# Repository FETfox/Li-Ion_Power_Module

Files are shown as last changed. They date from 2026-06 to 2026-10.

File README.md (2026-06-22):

## Status

  **RevA** In development (schematic complete, layout pending)

## Key Components

| Function | IC | Notes |
|---|----|----|
| Charger | BQ24074 | USB100/500 + ILIM modes |
| Protection | BQ29728 | OCP/OVP/UVP |
| Fuel Gauge | BQ27427 | Coulomb counter |
| Buck-Boost | TPS63020 | ~1.8-5.5V input, 3.3V/5V output |
| MCU (Smart) | ATtiny3217 | CAN interface logic |
| CAN Controller | MCP2515 | SPI interface |
| CAN Transceiver | SN65HVD230 | ISO11898-2 compliant |

## Usage

Battery powered 5w power supply for projects that use 3v3 or 5v.
The smart version tracks system status and communicates over CAN bus.

## Known Issues / TODOs

- [ ] PCB layout and thermal analysis
- [ ] Publish assembly guide and test procedure

## License

CC0

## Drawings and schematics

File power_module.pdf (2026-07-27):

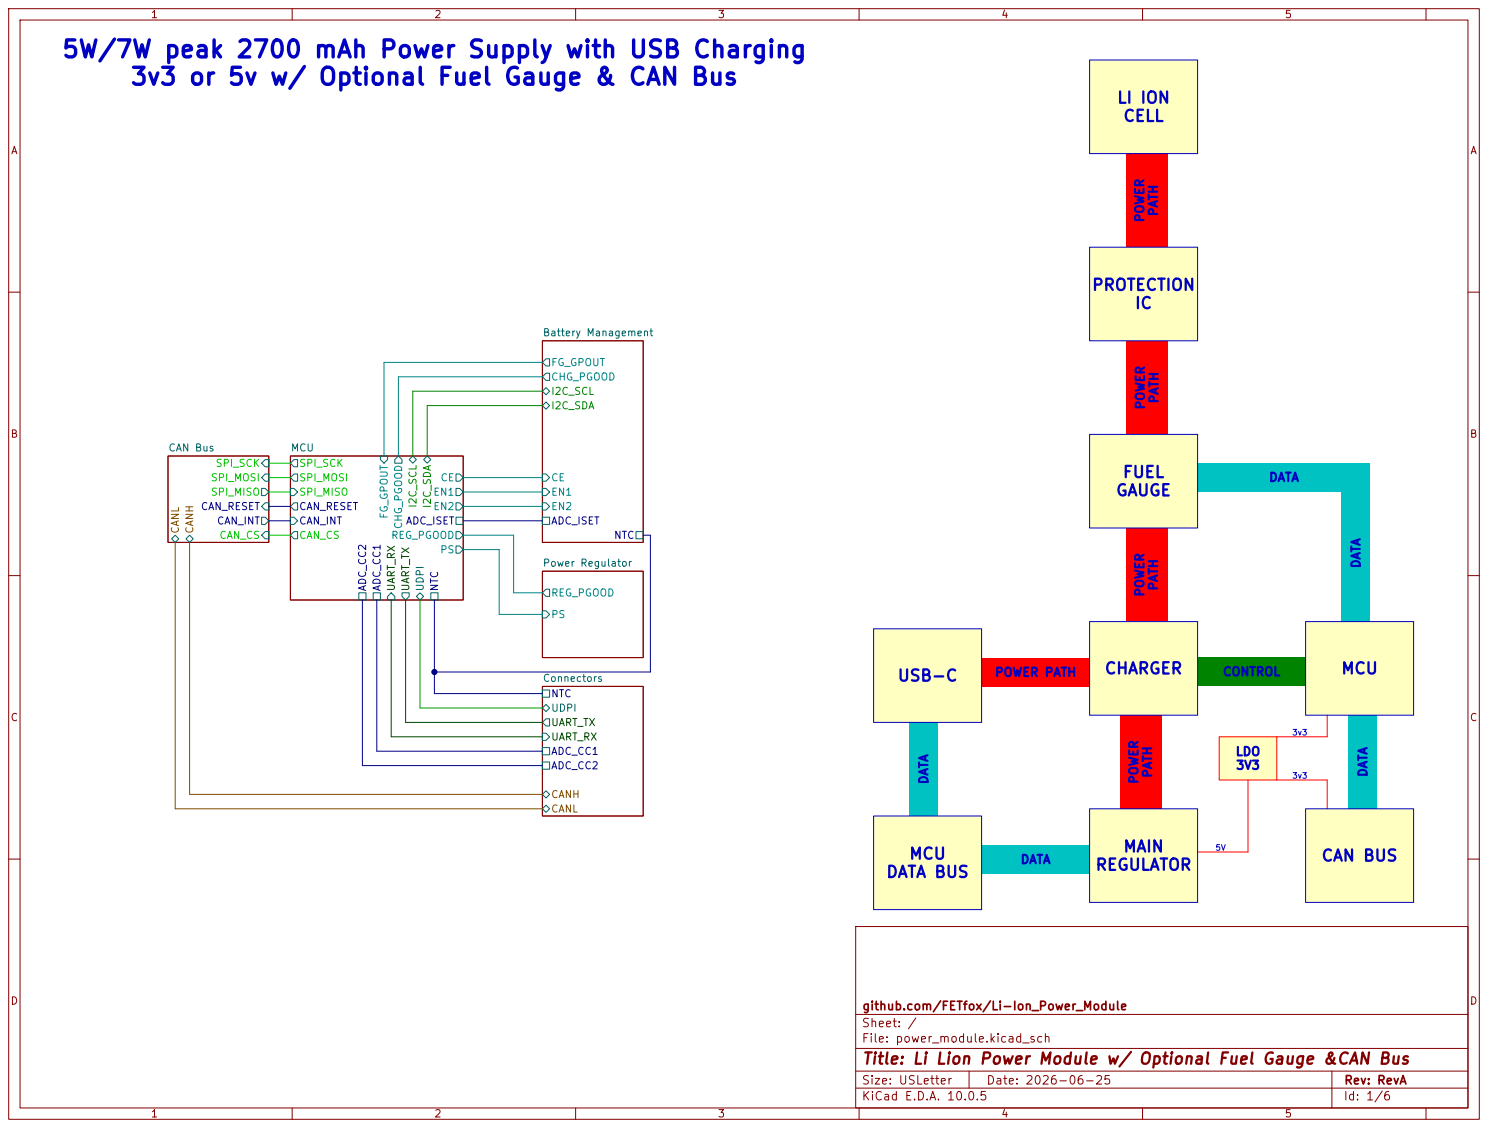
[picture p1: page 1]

5W/7W peak 2700 mAh Power Supply with USB Charging
3v3 or 5v w/ Optional Fuel Gauge & CAN Bus

LI ION
CELLPOWER PATH POWER PATH

Sheet: /
File: power_module.kicad_sch
Title: Li Lion Power Module w/ Optional Fuel Gauge &CAN Bus

Size: USLetter | Rev: RevA
KiCad E.D.A. 10.0.5 | Id: 1/6

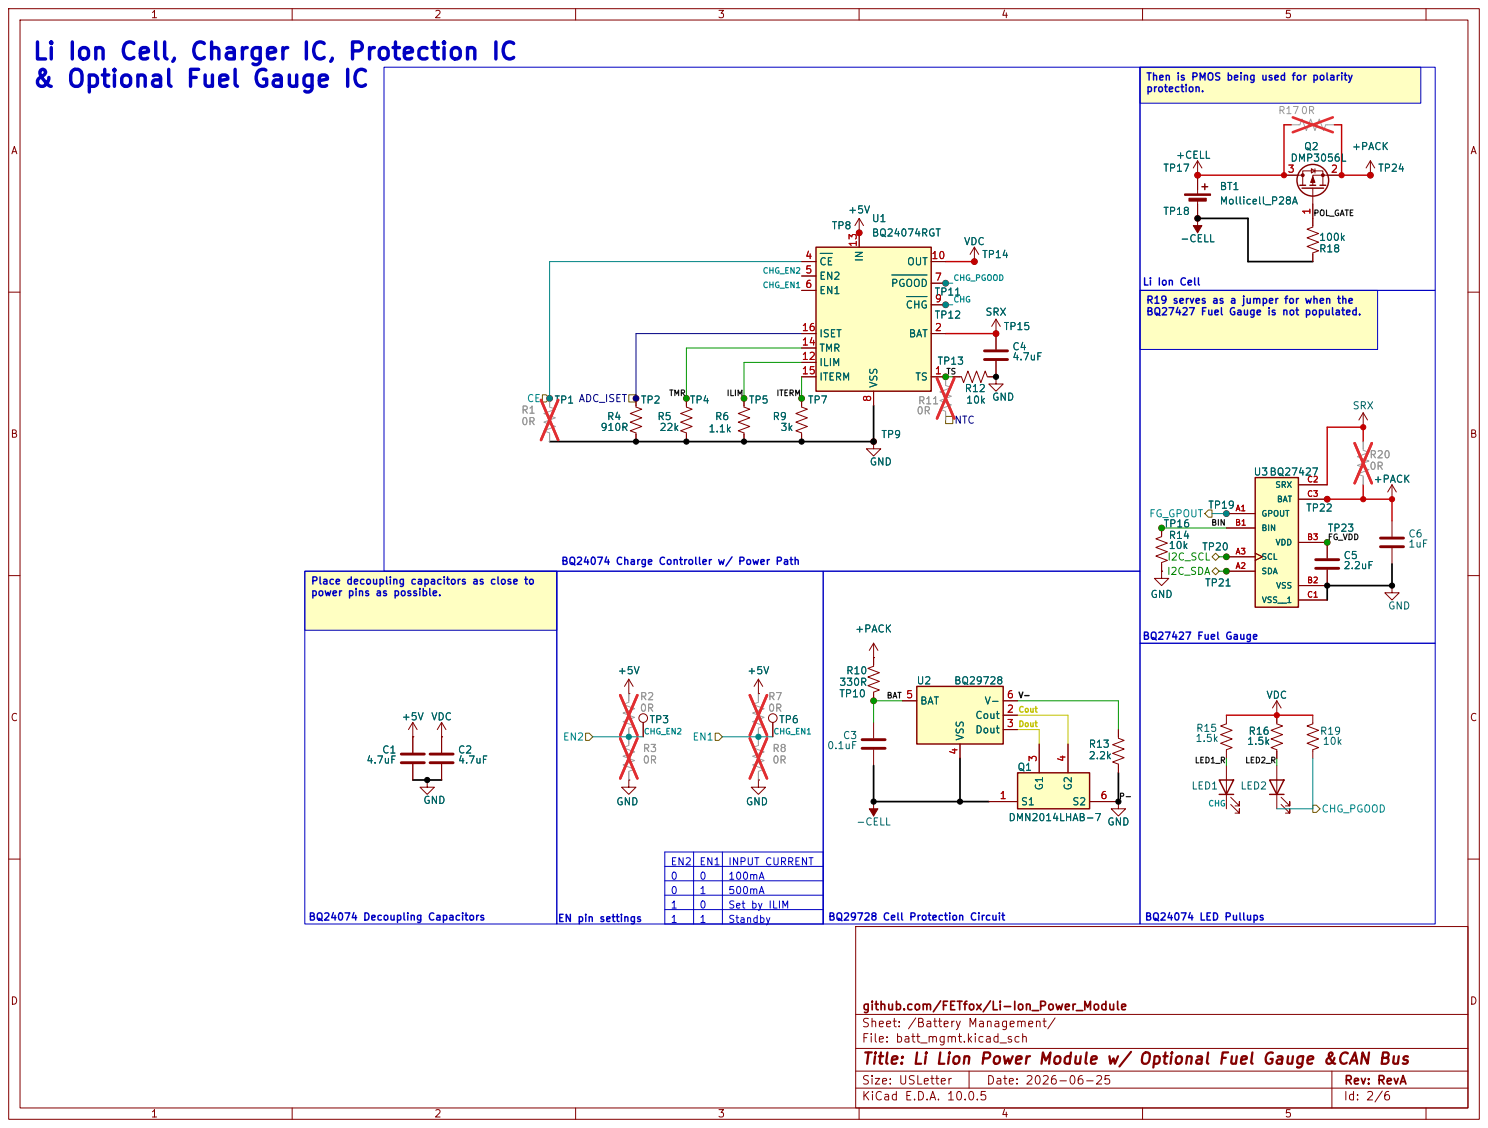
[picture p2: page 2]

BQ24074 Charge Controller w/ Power Path Li Ion Cell, Charger IC, Protection IC
& Optional Fuel Gauge IC

R19 serves as a jumper for when the BQ27427 Fuel Gauge is not populated. Then is PMOS being used for polarity
POL_GATE CHG
Li Ion Cell BQ27427 Fuel GaugeU3 BQ27427

protection. Place decoupling capacitors as close to

power pins as possible.

github.com/FETfox/Li-Ion_Power_Module
Sheet: /Battery Management/
File: batt_mgmt.kicad_sch
Title: Li Lion Power Module w/ Optional Fuel Gauge &CAN Bus

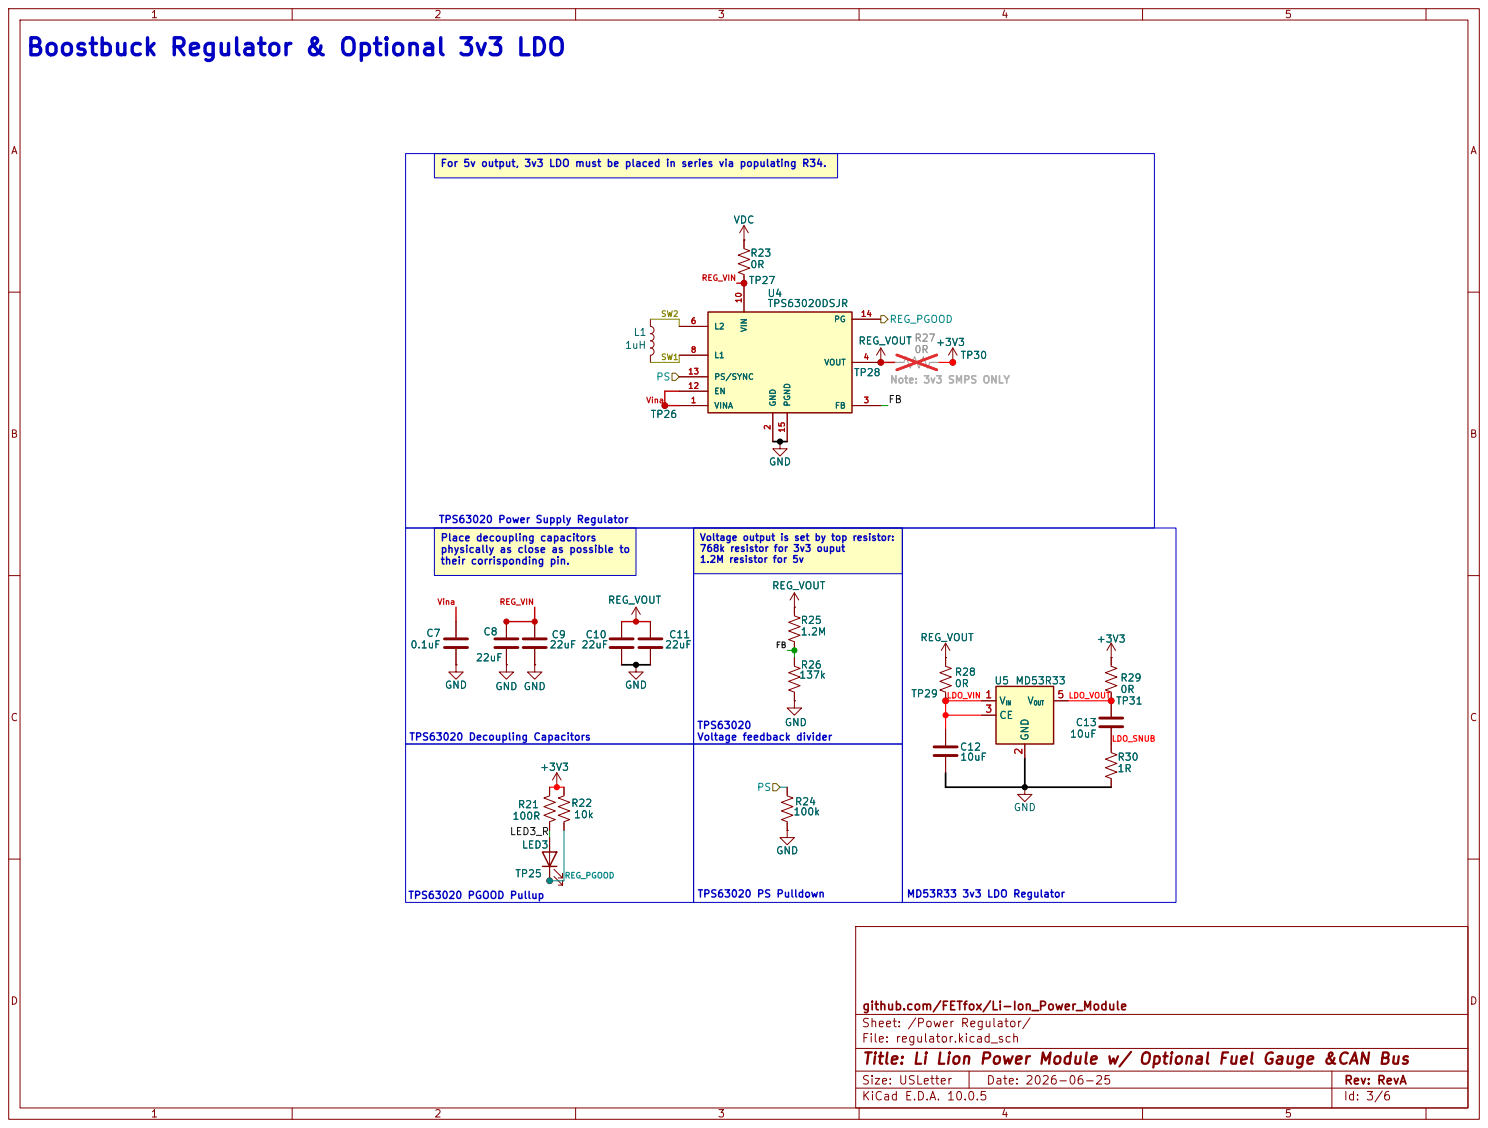
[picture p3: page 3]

Boostbuck Regulator & Optional 3v3 LDO

Voltage output is set by top resistor: 768k resistor for 3v3 ouput 1.2M resistor for 5v For 5v output, 3v3 LDO must be placed in series via populating R34. Place decoupling capacitors
TPS63020DSJR

physically as close as possible to

github.com/FETfox/Li-Ion_Power_Module
Sheet: /Power Regulator/
File: regulator.kicad_sch
Title: Li Lion Power Module w/ Optional Fuel Gauge &CAN Bus

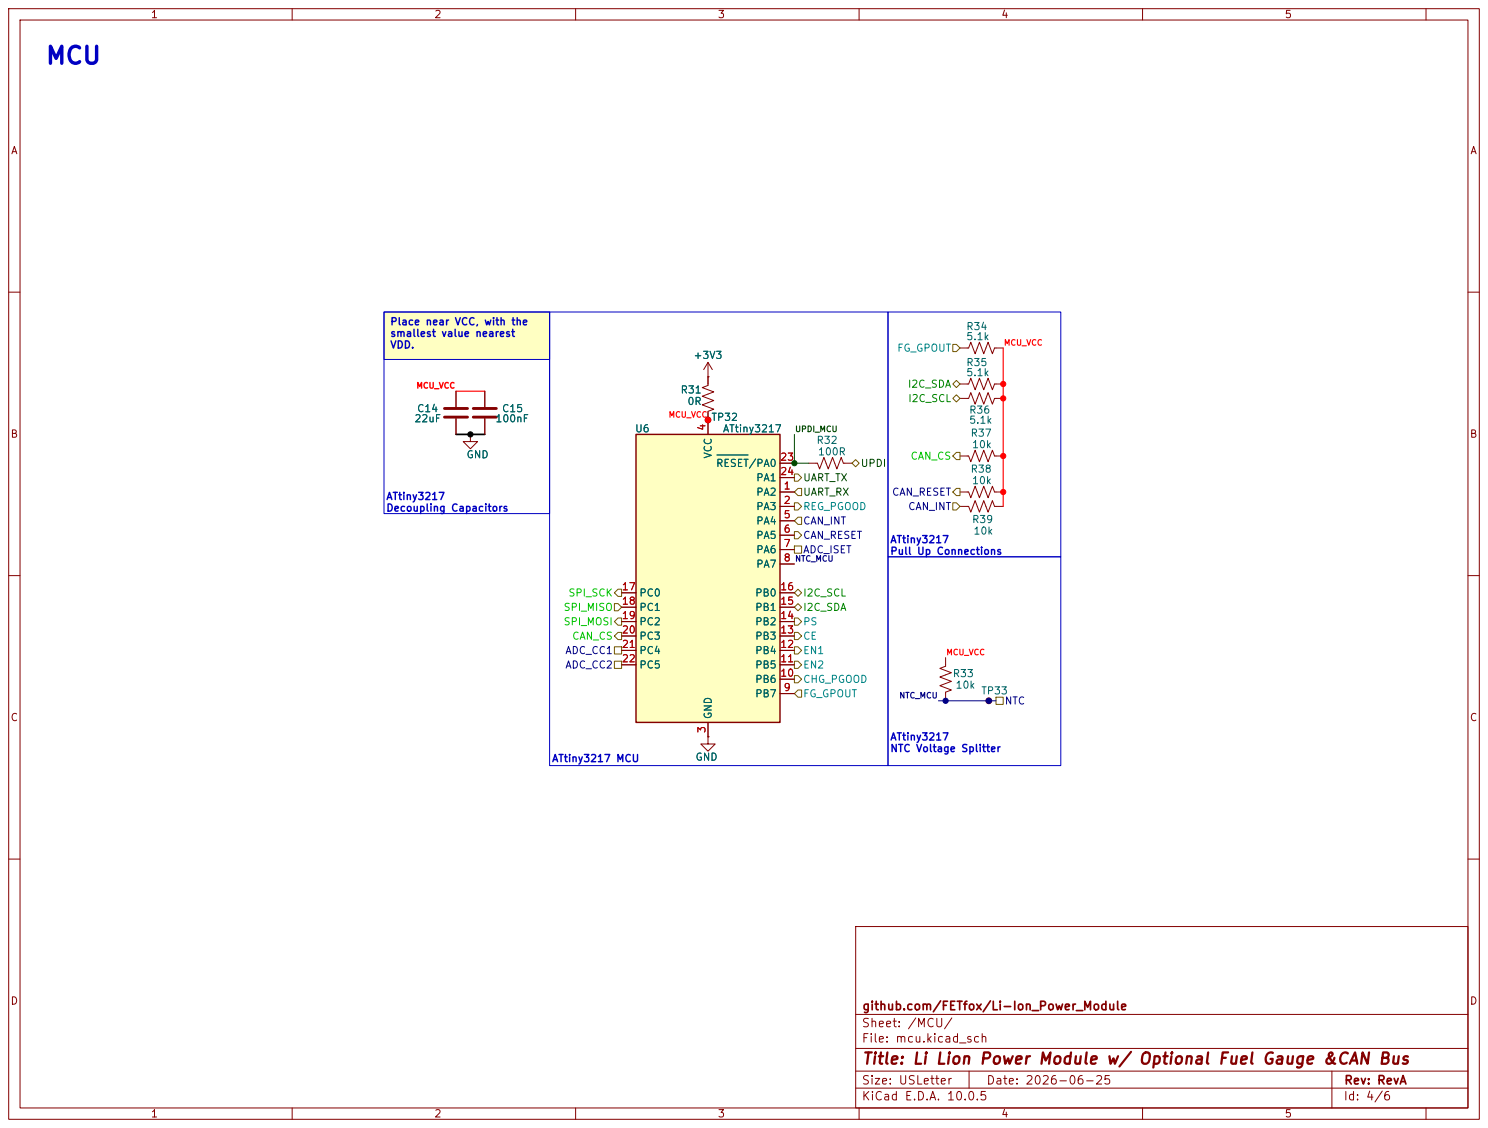
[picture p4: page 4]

smallest value nearest VDD. MCU

ATtiny3217 Pull Up Connections ATtiny3217 NTC Voltage Splitter +3V3

github.com/FETfox/Li-Ion_Power_Module
Sheet: /MCU/
File: mcu.kicad_sch
Title: Li Lion Power Module w/ Optional Fuel Gauge &CAN Bus

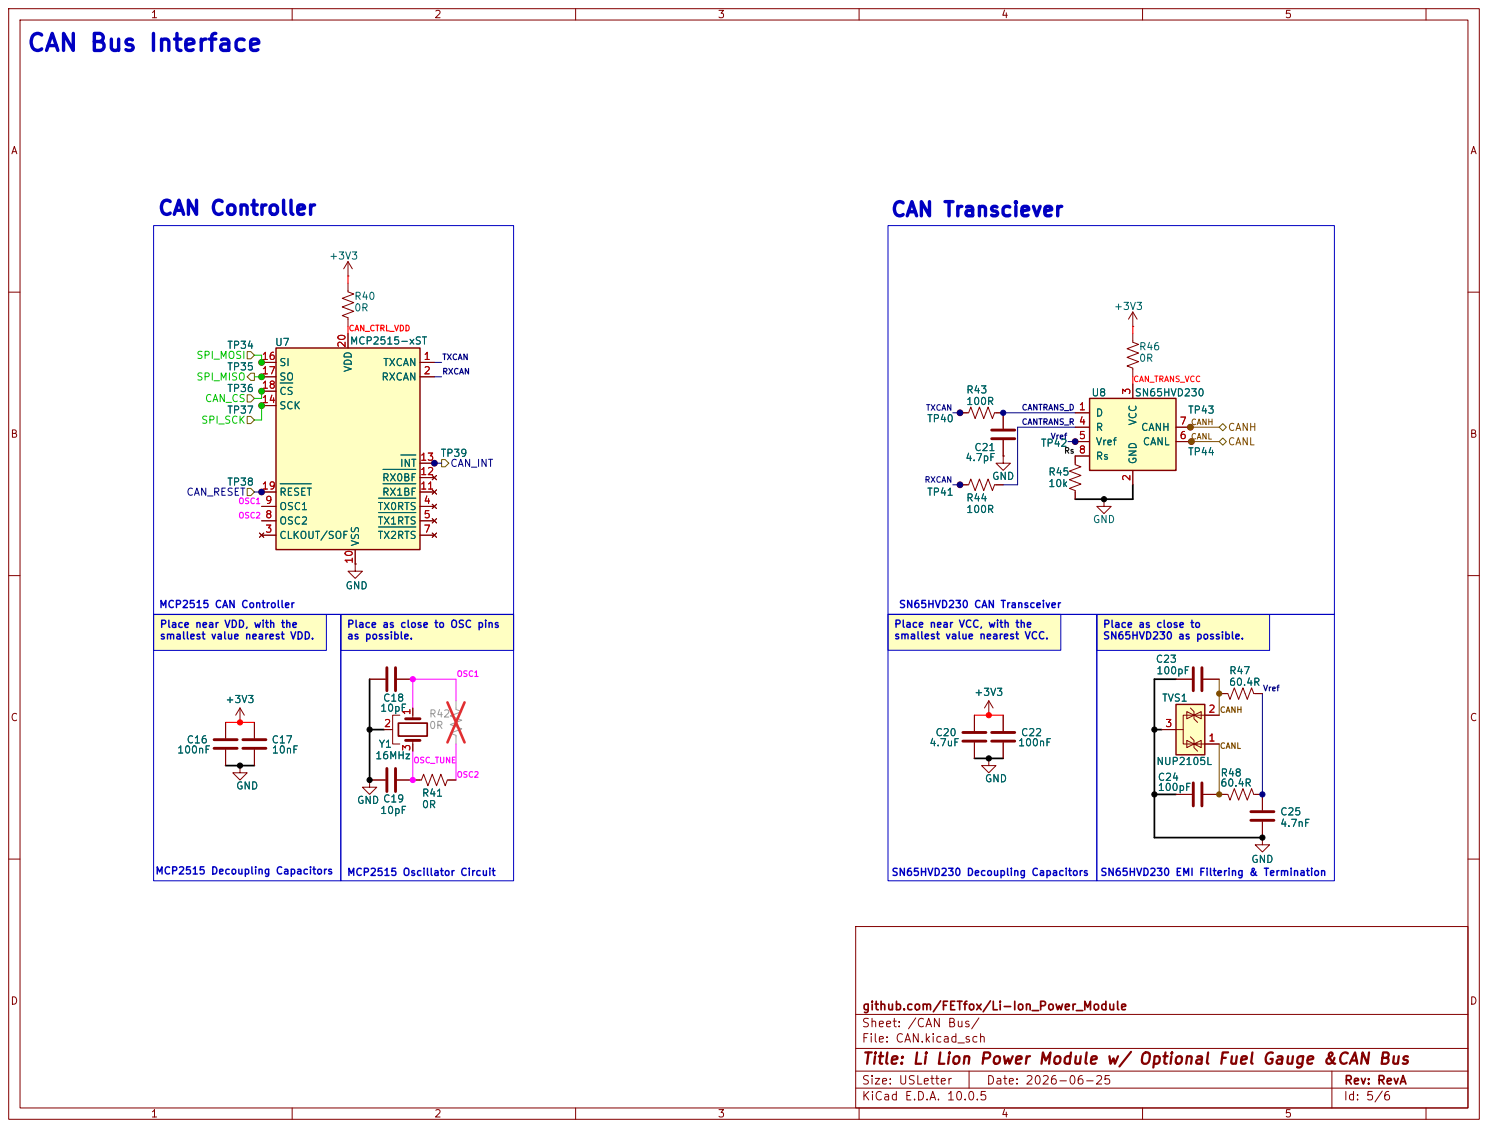
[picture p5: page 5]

smallest value nearest VDD. CAN Bus Interface

Vref CAN_TRANS_VCC Place as close to SN65HVD230 as possible. Place near VCC, with the

smallest value nearest VCC. Place as close to OSC pins as possible. Place near VDD, with the

github.com/FETfox/Li-Ion_Power_Module
Sheet: /CAN Bus/
File: CAN.kicad_sch
Title: Li Lion Power Module w/ Optional Fuel Gauge &CAN Bus

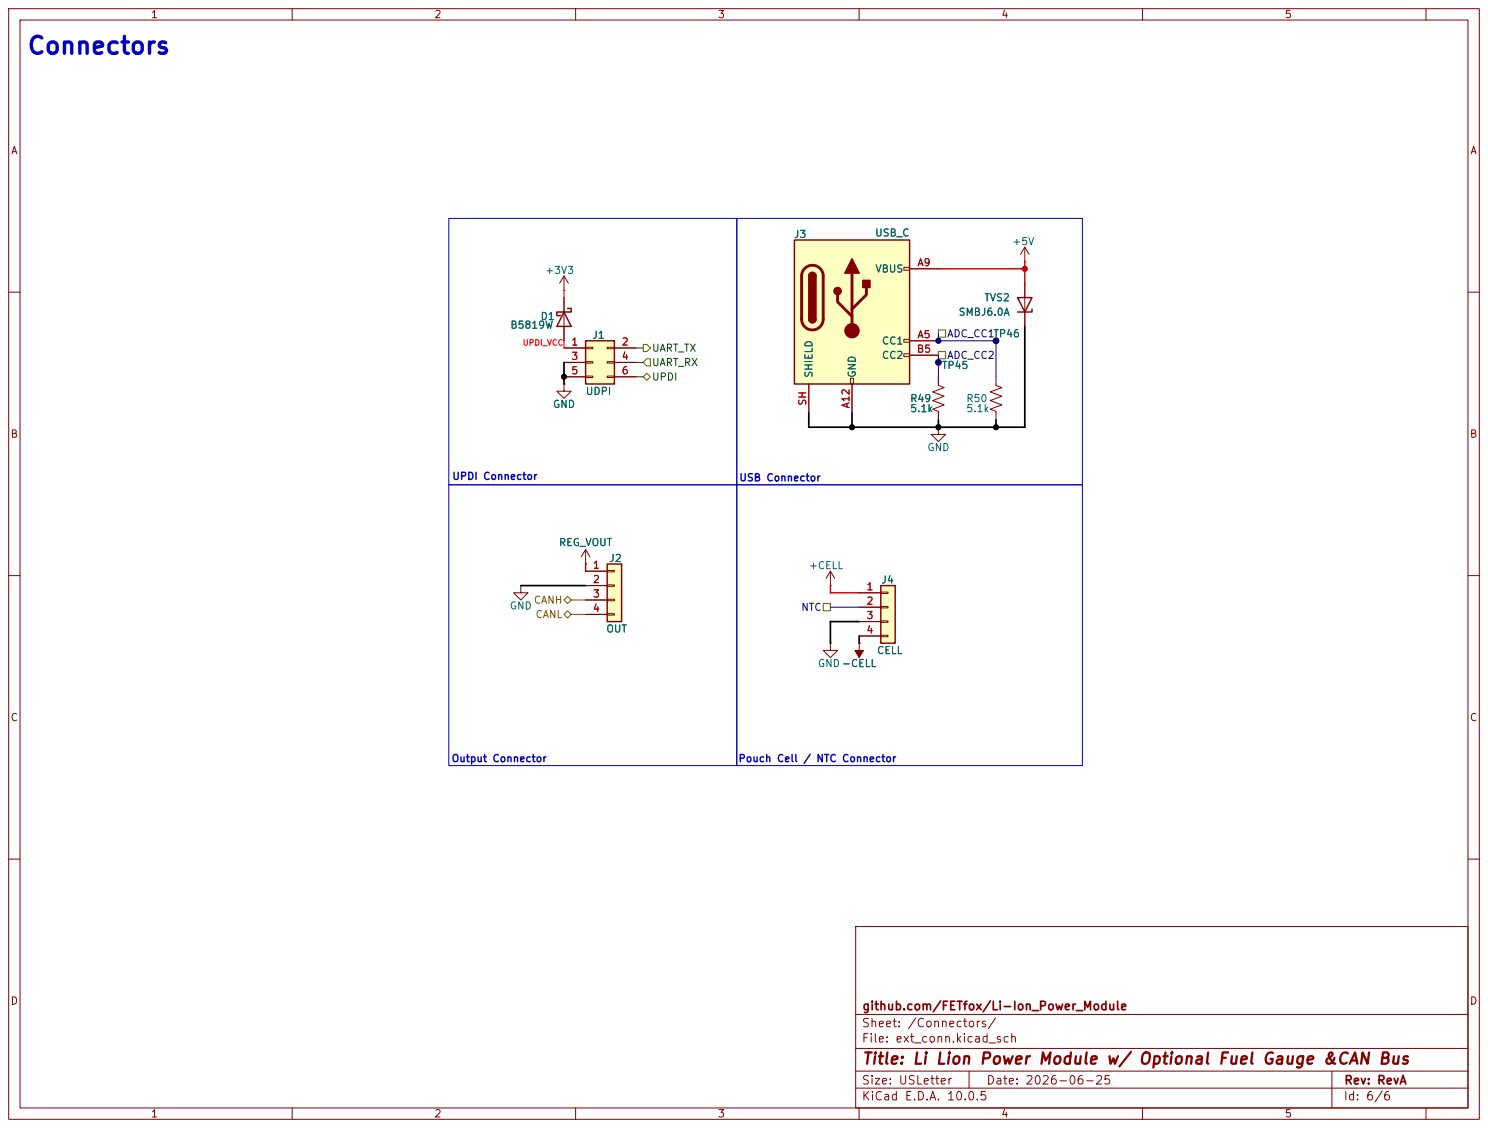
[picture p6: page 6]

github.com/FETfox/Li-Ion_Power_Module
Sheet: /Connectors/
File: ext_conn.kicad_sch
Title: Li Lion Power Module w/ Optional Fuel Gauge &CAN Bus

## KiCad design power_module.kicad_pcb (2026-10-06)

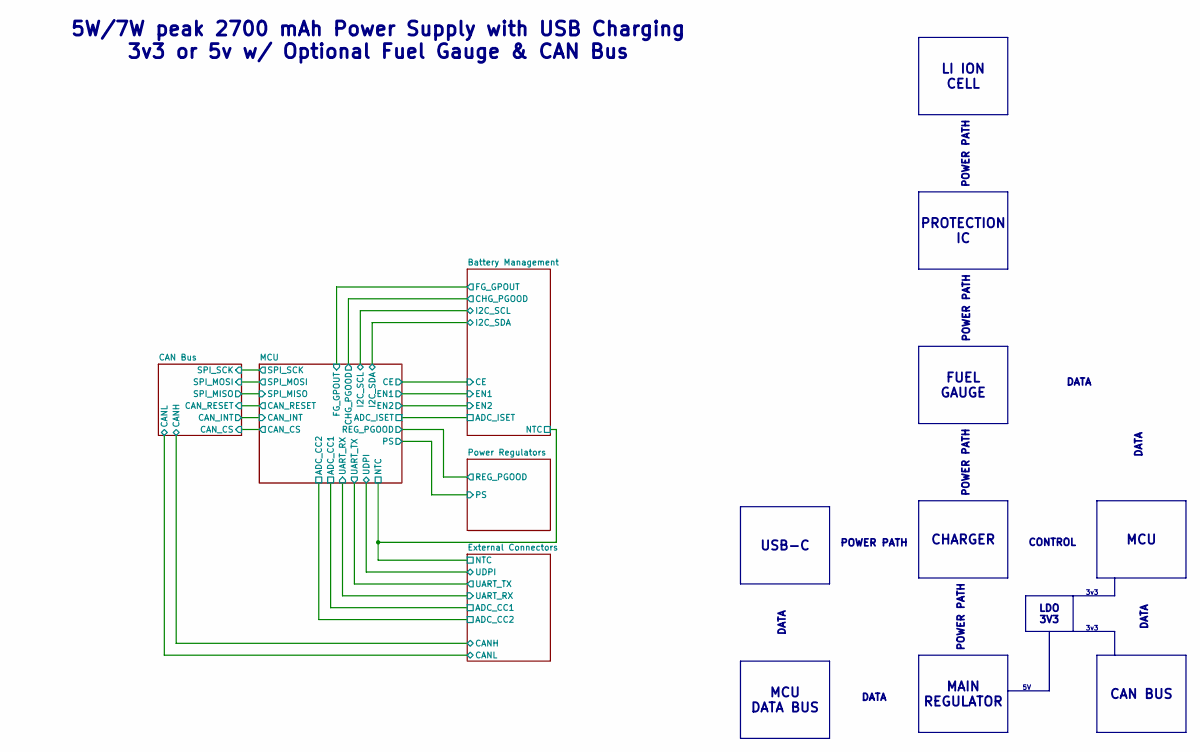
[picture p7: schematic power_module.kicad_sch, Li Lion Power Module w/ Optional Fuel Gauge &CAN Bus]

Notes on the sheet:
3v3
5W/7W peak 2700 mAh Power Supply with USB Charging 3v3 or 5v w/ Optional Fuel Gauge & CAN Bus
LDO 3V3
FUEL GAUGE
MCU DATA BUS
DATA
CHARGER
POWER PATH
USB-C
CAN BUS
MAIN REGULATOR
PROTECTION IC
LI ION CELL
MCU
CONTROL

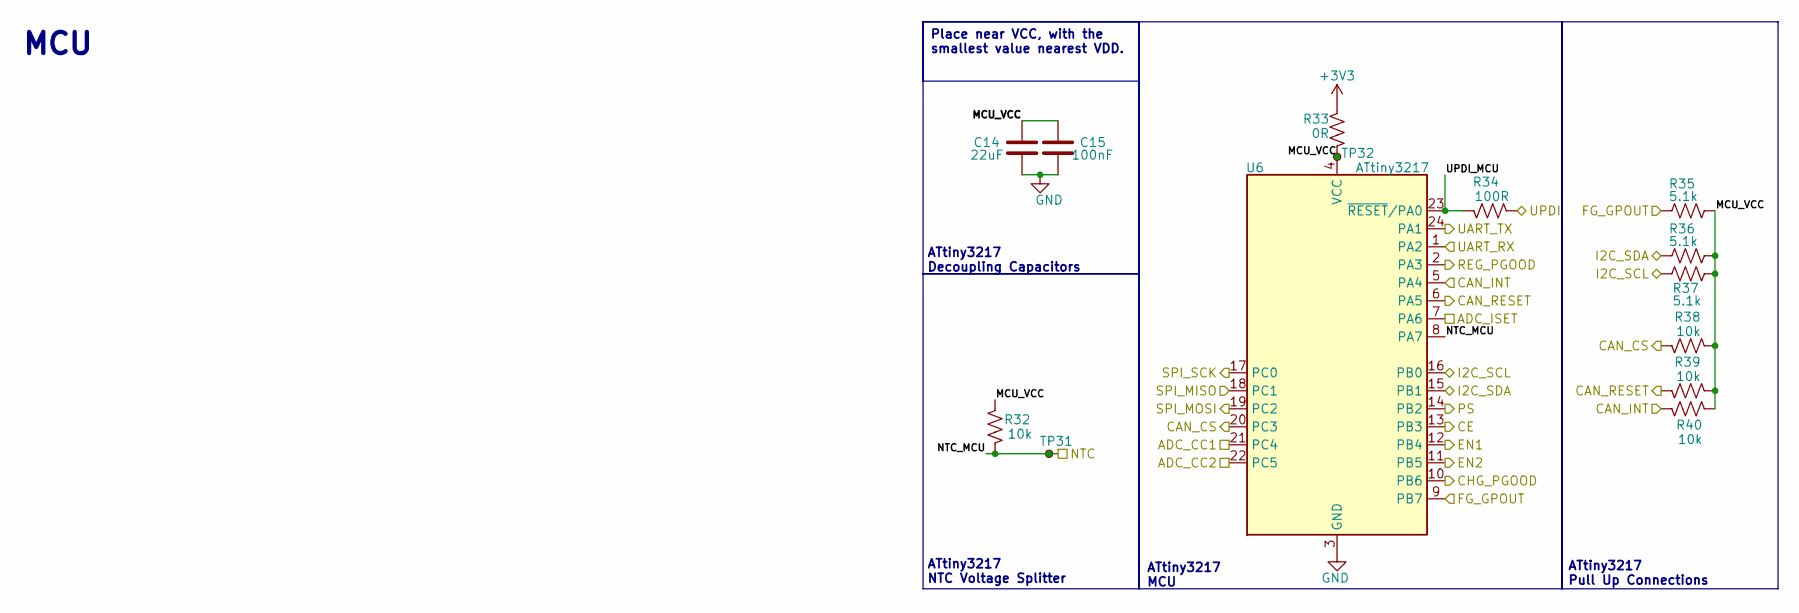
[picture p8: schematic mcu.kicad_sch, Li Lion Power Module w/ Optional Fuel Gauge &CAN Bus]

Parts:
C14: 22uF; C_0805_2012Metric; LCSC# C77074
C15: 100nF; C_0603_1608Metric; LCSC# C14663
R32, R38, R39, R40: 10k; R_0603_1608Metric; MFR# RC0603FR-0710KL; LCSC# C98220
R33: 0R; R_0805_2012Metric; LCSC# C54921246
R34: 100R; R_0603_1608Metric; MFR# RC0603FR-07100RL; LCSC# C105588
R35, R36, R37: 5.1k; R_0603_1608Metric; MFR# RC0603FR-075K1L; LCSC# C105580
TP31: NTC; TestPoint_Pad_D1.0mm
TP32: MCU_VCC; TestPoint_Pad_D1.0mm
U6: ATtiny3217; QFN-24-1EP_4x4mm_P0.5mm_EP2.6x2.6mm; LCSC# C15193

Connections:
+3V3: R33.1; also elsewhere on the board
/Battery Management/ADC_ISET: U6.7 (PA6); also elsewhere on the board
/Battery Management/CE: U6.13 (PB3); also elsewhere on the board
/Battery Management/CHG_EN1: U6.12 (PB4); also elsewhere on the board
/Battery Management/CHG_EN2: U6.11 (PB5); also elsewhere on the board
/Battery Management/CHG_PGOOD: U6.10 (PB6); also elsewhere on the board
/Battery Management/FG_GPOUT: R35.1, U6.9 (PB7); also elsewhere on the board
/Battery Management/I2C_SCL: R37.2, U6.16 (PB0); also elsewhere on the board
/Battery Management/I2C_SDA: R36.1, U6.15 (PB1); also elsewhere on the board
/CAN Bus/CAN_CS: R38.2, U6.20 (PC3); also elsewhere on the board
/CAN Bus/CAN_INT: R40.1, U6.5 (PA4); also elsewhere on the board
/CAN Bus/CAN_RESET: R39.2, U6.6 (PA5); also elsewhere on the board
/CAN Bus/SPI_MISO: U6.18 (PC1); also elsewhere on the board
/CAN Bus/SPI_MOSI: U6.19 (PC2); also elsewhere on the board
/CAN Bus/SPI_SCK: U6.17 (PC0); also elsewhere on the board
/External Connectors/ADC_CC1: U6.21 (PC4); also elsewhere on the board
/External Connectors/ADC_CC2: U6.22 (PC5); also elsewhere on the board
/External Connectors/UART_RX: U6.1 (PA2); also elsewhere on the board
/External Connectors/UART_TX: U6.24 (PA1); also elsewhere on the board
/MCU/MCU_VCC: C14.2, C15.2, R32.2, R33.2, R35.2, R36.2, R37.1, R38.1, R39.1, R40.2, TP32.1 (1_1), U6.4 (VCC)
/MCU/NTC_MCU: R32.1, TP31.1 (1_1), U6.8 (PA7); also elsewhere on the board
/MCU/PS: U6.14 (PB2); also elsewhere on the board
/MCU/UPDI: R34.2
/MCU/UPDI_MCU: R34.1, U6.23 (~RESET/PA0)
/Power Regulators/REG_PGOOD: U6.2 (PA3); also elsewhere on the board
GND: C14.1, C15.1, U6.3 (GND), U6.25 (GND); also elsewhere on the board

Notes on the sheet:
ATtiny3217 Pull Up Connections
ATtiny3217 MCU
MCU
ATtiny3217 NTC Voltage Splitter
ATtiny3217 Decoupling Capacitors
Place near VCC, with the smallest value nearest VDD.

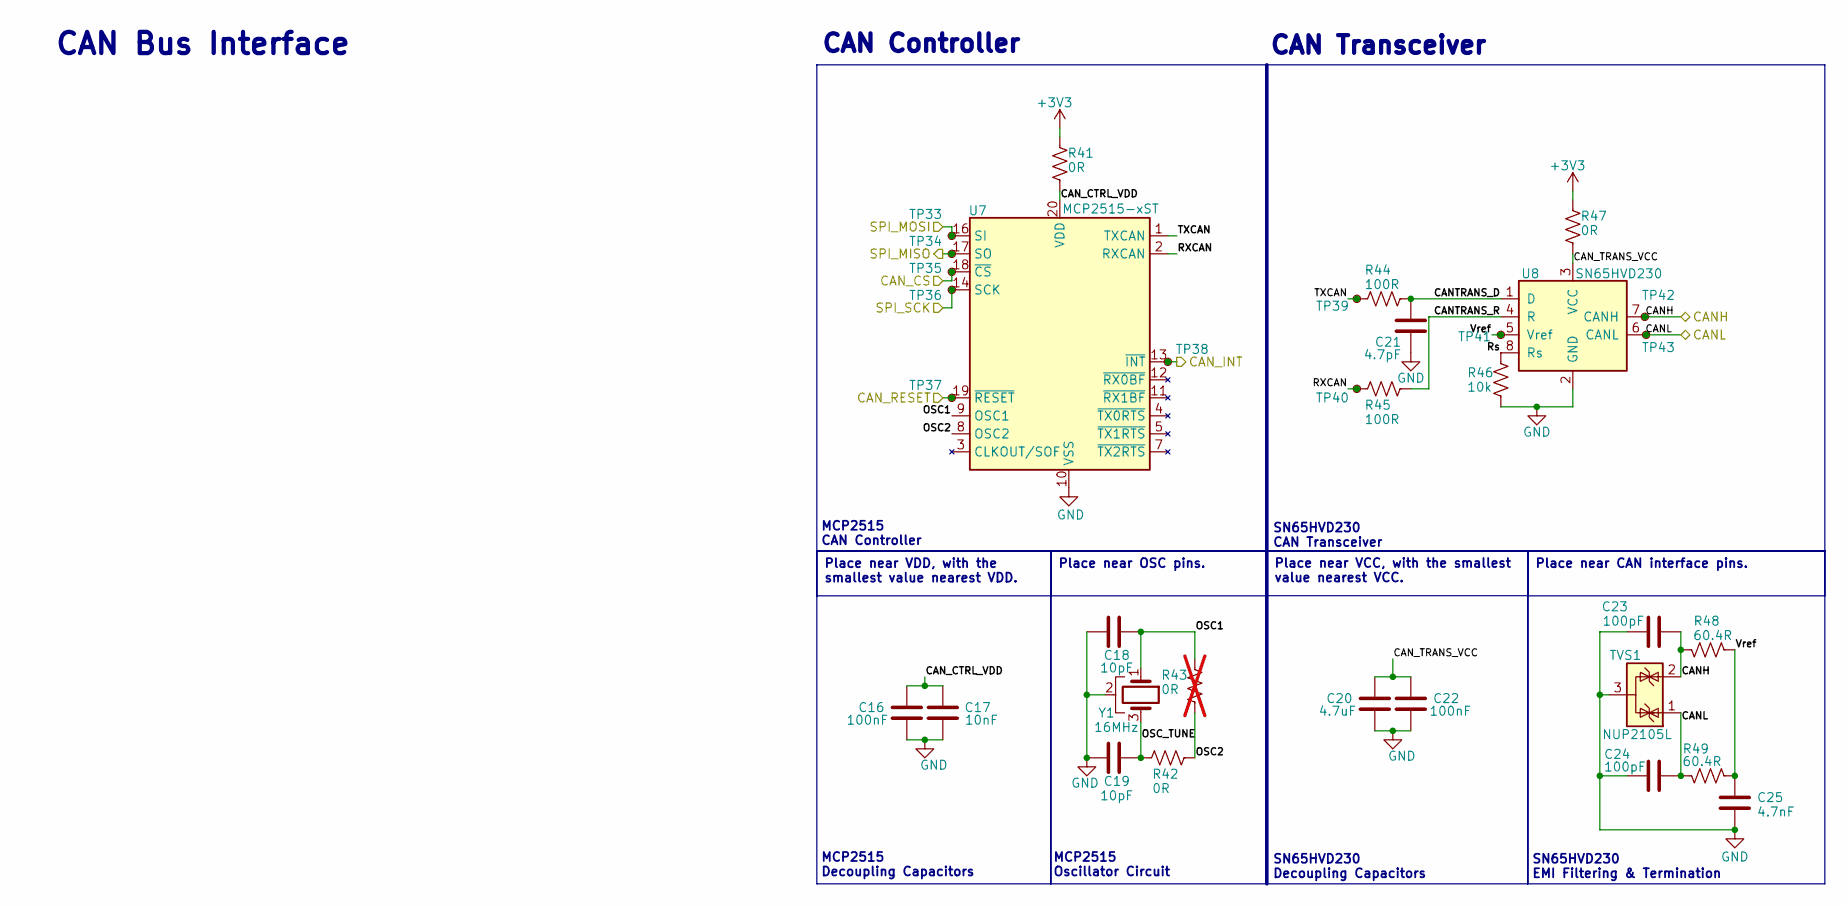
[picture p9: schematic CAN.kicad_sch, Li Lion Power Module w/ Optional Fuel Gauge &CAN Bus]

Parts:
C16, C22: 100nF; C_0603_1608Metric; LCSC# C14663
C17: 10nF; C_0603_1608Metric; LCSC# C100042
C18, C19: 10pF; C_0603_1608Metric; LCSC# C106245
C20: 4.7uF; C_0805_2012Metric; LCSC# C96454
C21: 4.7pF; C_0603_1608Metric; LCSC# C1669
C23, C24: 100pF; C_0603_1608Metric; LCSC# C14858
C25: 4.7nF; C_0603_1608Metric; LCSC# C16194364
R41, R42, R47: 0R; R_0805_2012Metric; LCSC# C54921246
R43: 0R; R_0805_2012Metric; LCSC# C54921246; not fitted
R44, R45: 100R; R_0603_1608Metric; LCSC# C105588
R46: 10k; R_0603_1608Metric; LCSC# C98220
R48, R49: 60.4R; R_0603_1608Metric; LCSC# C245987
TP33: SPI_MOSI; TestPoint_Pad_D1.0mm
TP34: SPI_MISO; TestPoint_Pad_D1.0mm
TP35: CAN_CS; TestPoint_Pad_D1.0mm
TP36: SPI_SCK; TestPoint_Pad_D1.0mm
TP37: CAN_RESET; TestPoint_Pad_D1.0mm
TP38: CAN_INT; TestPoint_Pad_D1.0mm
TP39: TXCAN; TestPoint_Pad_D1.0mm
TP40: RXCAN; TestPoint_Pad_D1.0mm
TP41: VREF; TestPoint_Pad_D1.0mm
TP42: CANH; TestPoint_Pad_D1.0mm
TP43: CANL; TestPoint_Pad_D1.0mm
TVS1: NUP2105L; SOT-23; MFR# NUP2105LT1G; LCSC# C14486
U7: MCP2515-xST; TSSOP-20_4.4x6.5mm_P0.65mm; LCSC# C15193
U8: SN65HVD230; SOIC-8_3.9x4.9mm_P1.27mm; LCSC# C12084
Y1: 16MHz; Crystal_SMD_3225-4Pin_3.2x2.5mm; MFR# X322516MLB4SI; LCSC# C13738

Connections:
+3V3: R41.1, R47.1; also elsewhere on the board
/CAN Bus/CANH: C23.2, R48.2, TP42.1 (1_1), TVS1.2 (K), U8.7 (CANH); also elsewhere on the board
/CAN Bus/CANL: C24.1, R49.1, TP43.1 (1_1), TVS1.1 (K), U8.6 (CANL); also elsewhere on the board
/CAN Bus/CANTRANS_D: C21.1, R44.2, U8.1 (D)
/CAN Bus/CANTRANS_R: R45.1, U8.4 (R)
/CAN Bus/CAN_CS: TP35.1 (1_1), U7.18 (~CS); also elsewhere on the board
/CAN Bus/CAN_CTRL_VDD: C16.2, C17.2, R41.2, U7.20 (VDD)
/CAN Bus/CAN_INT: TP38.1 (1_1), U7.13 (~INT); also elsewhere on the board
/CAN Bus/CAN_RESET: TP37.1 (1_1), U7.19 (~RESET); also elsewhere on the board
/CAN Bus/CAN_TRANS_VCC: C20.2, C22.2, R47.2, U8.3 (VCC)
/CAN Bus/OSC1: C18.2, R43.1, U7.9 (OSC1), Y1.1
/CAN Bus/OSC2: R42.2, R43.2, U7.8 (OSC2)
/CAN Bus/OSC_TUNE: C19.2, R42.1, Y1.3
/CAN Bus/RXCAN: R45.2, TP40.1 (1_1), U7.2 (RXCAN)
/CAN Bus/Rs: R46.2, U8.8 (Rs)
/CAN Bus/SPI_MISO: TP34.1 (1_1), U7.17 (SO); also elsewhere on the board
/CAN Bus/SPI_MOSI: TP33.1 (1_1), U7.16 (SI); also elsewhere on the board
/CAN Bus/SPI_SCK: TP36.1 (1_1), U7.14 (SCK); also elsewhere on the board
/CAN Bus/TXCAN: R44.1, TP39.1 (1_1), U7.1 (TXCAN)
/CAN Bus/Vref: C25.1, R48.1, R49.2, TP41.1 (1_1), U8.5 (Vref)
GND: C16.1, C17.1, C18.1, C19.1, C20.1, C21.2, C22.1, C23.1, C24.2, C25.2, R46.1, TVS1.3 (A), U7.10 (VSS), U8.2 (GND), Y1.2 (GND), Y1.4 (GND); also elsewhere on the board

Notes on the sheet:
CAN Transceiver
CAN Bus Interface
SN65HVD230 EMI Filtering & Termination
CAN Controller
MCP2515 Oscillator Circuit
SN65HVD230 CAN Transceiver
SN65HVD230 Decoupling Capacitors
MCP2515 Decoupling Capacitors
MCP2515 CAN Controller
Place near CAN interface pins.
Place near OSC pins.
Place near VCC, with the smallest value nearest VCC.
Place near VDD, with the smallest value nearest VDD.

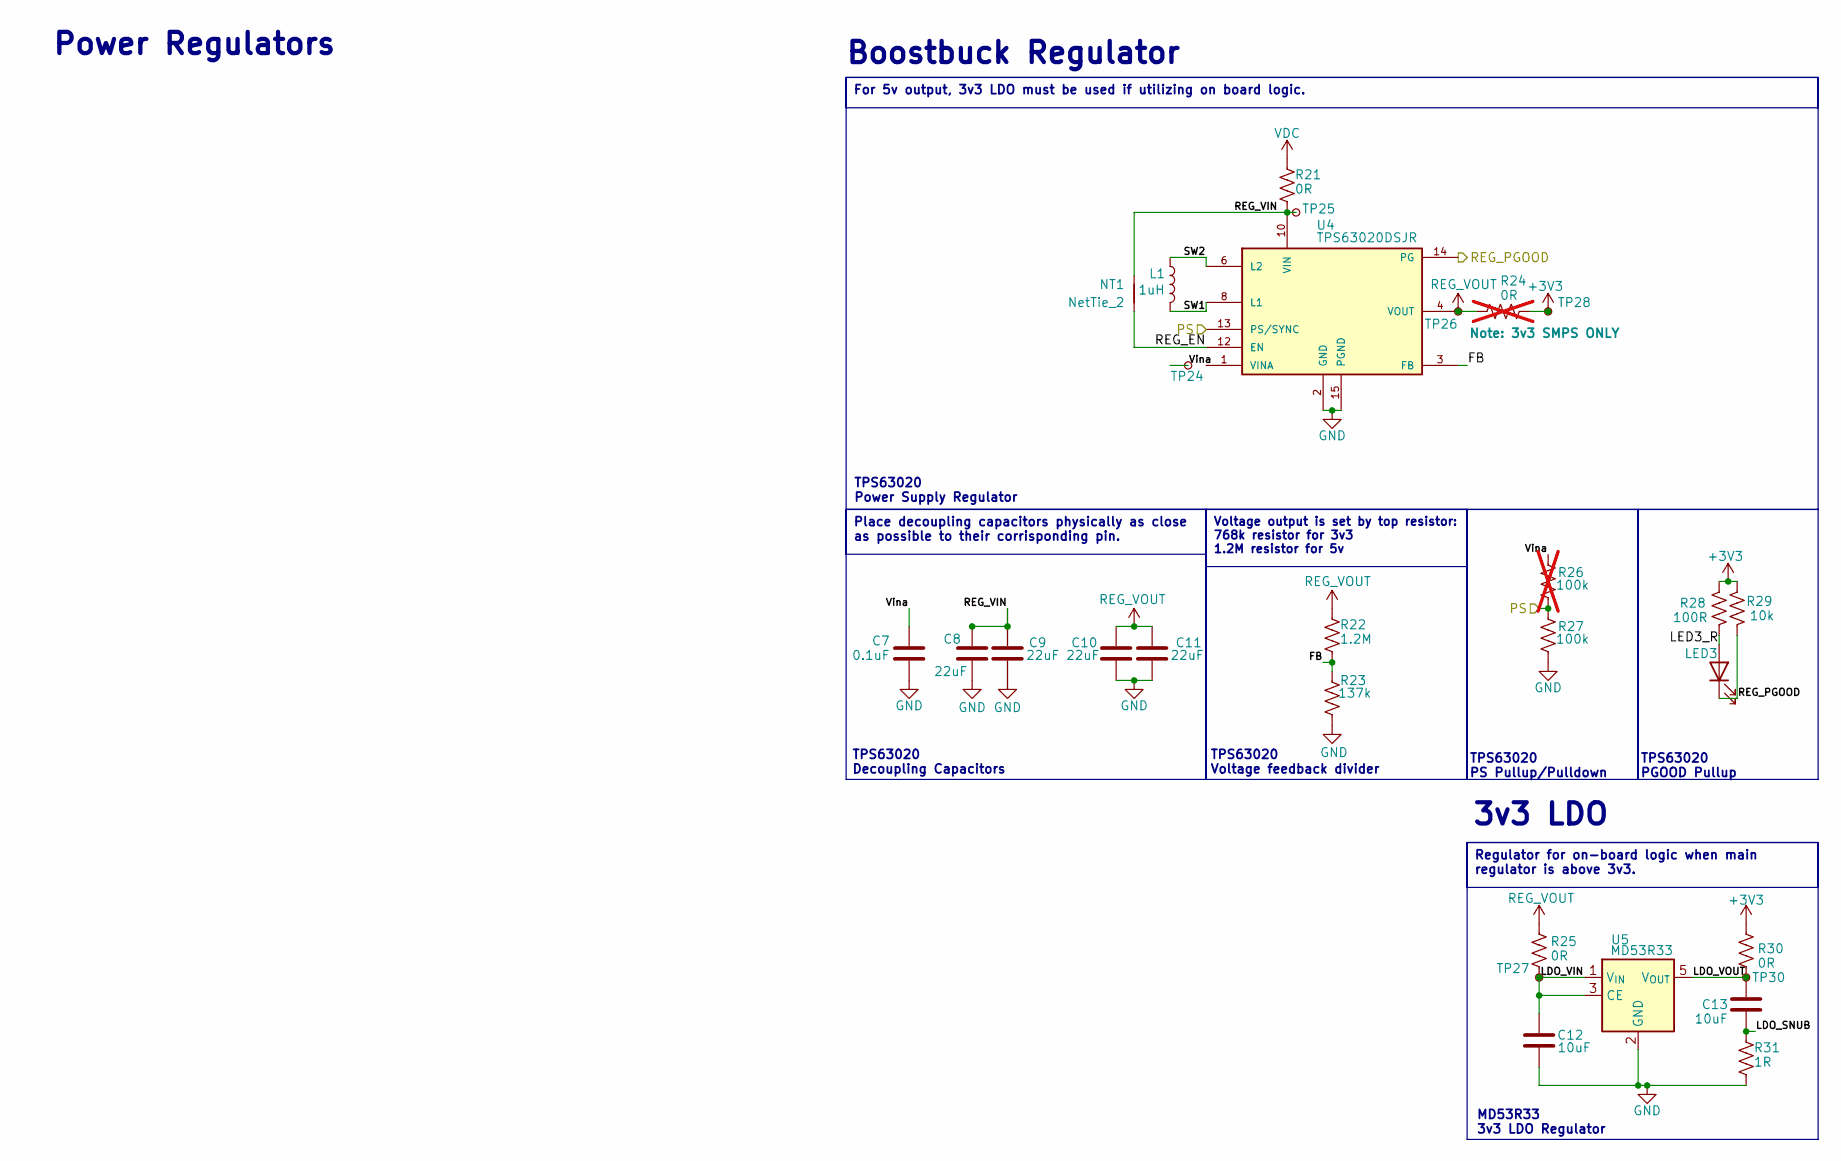
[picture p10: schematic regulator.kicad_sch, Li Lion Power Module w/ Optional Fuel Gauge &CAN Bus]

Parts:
C7: 0.1uF; C_0603_1608Metric; LCSC# C14663
C8, C9, C10, C11: 22uF; C_0805_2012Metric; LCSC# C77074
C12, C13: 10uF; C_0603_1608Metric; LCSC# C90053
L1: 1uH; DR73; MFR# DR73-1R0-R; LCSC# C2454006
LED3: PGOOD; LED_0603_1608Metric; LCSC# C2286
NT1: NetTie_2; NetTie-2_SMD_Pad2.0mm
R21: 0R; R_1206_3216Metric; MFR# HP06W2J0000T5E; LCSC# C473612
R22: 1.2M; R_0603_1608Metric; MFR# RC0603FR-071M2L; LCSC# C137774
R23: 137k; R_0603_1608Metric; MFR# RC0603FR-07137KL; LCSC# C137797
R24: 0R; R_1206_3216Metric; MFR# HP06W2J0000T5E; LCSC# C473612; not fitted
R25, R30: 0R; R_0805_2012Metric; LCSC# C54921246
R26: 100k; R_0603_1608Metric; MFR# RC0603FR-07100KL; LCSC# C14675; not fitted
R27: 100k; R_0603_1608Metric; MFR# RC0603FR-07100KL; LCSC# C14675
R28: 100R; R_0603_1608Metric; MFR# RC0603FR-07100RL; LCSC# C105588
R29: 10k; R_0603_1608Metric; MFR# RC0603FR-0710KL; LCSC# C98220
R31: 1R; R_0603_1608Metric; MFR# RC0603FR-071RL; LCSC# C112305
TP24: REG_Vina; TestPoint_Pad_D1.0mm
TP25: REG_VIN; TestPoint_Pad_D1.0mm
TP26: REG_OUT; TestPoint_Pad_D1.0mm
TP27: LDO_VIN; TestPoint_Pad_D1.0mm
TP28: +3v3; TestPoint_Pad_D1.0mm
TP30: LDO_VOUT; TestPoint_Pad_D1.0mm
U4: TPS63020DSJR; IC_TPS63020DSJR; MFR# TPS63020DSJR; LCSC# C15483
U5: MD53R33; SOT-23-5; MFR# MD53R33; LCSC# C111685

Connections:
+3V3: R24.2, R28.2, R29.2, R30.2, TP28.1 (1_1); also elsewhere on the board
/MCU/PS: R26.2, R27.1, U4.13 (PS/SYNC); also elsewhere on the board
/Power Regulators/FB: R22.2, R23.1, U4.3 (FB)
/Power Regulators/LDO_SNUB: C13.2, R31.1
/Power Regulators/LDO_VIN: C12.1, R25.1, TP27.1 (1_1), U5.1 (V_{IN}), U5.3 (CE)
/Power Regulators/LDO_VOUT: C13.1, R30.1, TP30.1 (1_1), U5.5 (V_{OUT})
/Power Regulators/LED3_R: LED3.2 (A), R28.1
/Power Regulators/REG_EN: NT1.1, U4.12 (EN)
/Power Regulators/REG_PGOOD: LED3.1 (K), R29.1, U4.14 (PG); also elsewhere on the board
/Power Regulators/REG_VIN: C8.1, C9.1, NT1.2, R21.2, TP25.1 (1_1), U4.10 (VIN), U4.11 (VIN)
/Power Regulators/SW1: L1.2, U4.8 (L1), U4.9 (L1)
/Power Regulators/SW2: L1.1, U4.6 (L2), U4.7 (L2)
/Power Regulators/Vina: C7.1, R26.1, TP24.1 (1_1)
GND: C7.2, C8.2, C9.2, C10.2, C11.2, C12.2, R23.2, R27.2, R31.2, U4.2 (GND), U4.15 (PGND), U5.2 (GND); also elsewhere on the board
REG_VOUT: C10.1, C11.1, R22.1, R24.1, R25.2, TP26.1 (1_1), U4.4 (VOUT), U4.5 (VOUT); also elsewhere on the board
VDC: R21.1; also elsewhere on the board

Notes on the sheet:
Power Regulators
3v3 LDO
Boostbuck Regulator
TPS63020 Decoupling Capacitors
MD53R33 3v3 LDO Regulator
TPS63020 Voltage feedback divider
TPS63020 PS Pullup/Pulldown
TPS63020 PGOOD Pullup
TPS63020 Power Supply Regulator
Place decoupling capacitors physically as close as possible to their corrisponding pin.
For 5v output, 3v3 LDO must be used if utilizing on board logic.
Voltage output is set by top resistor: 768k resistor for 3v3 1.2M resistor for 5v
Regulator for on-board logic when main regulator is above 3v3.

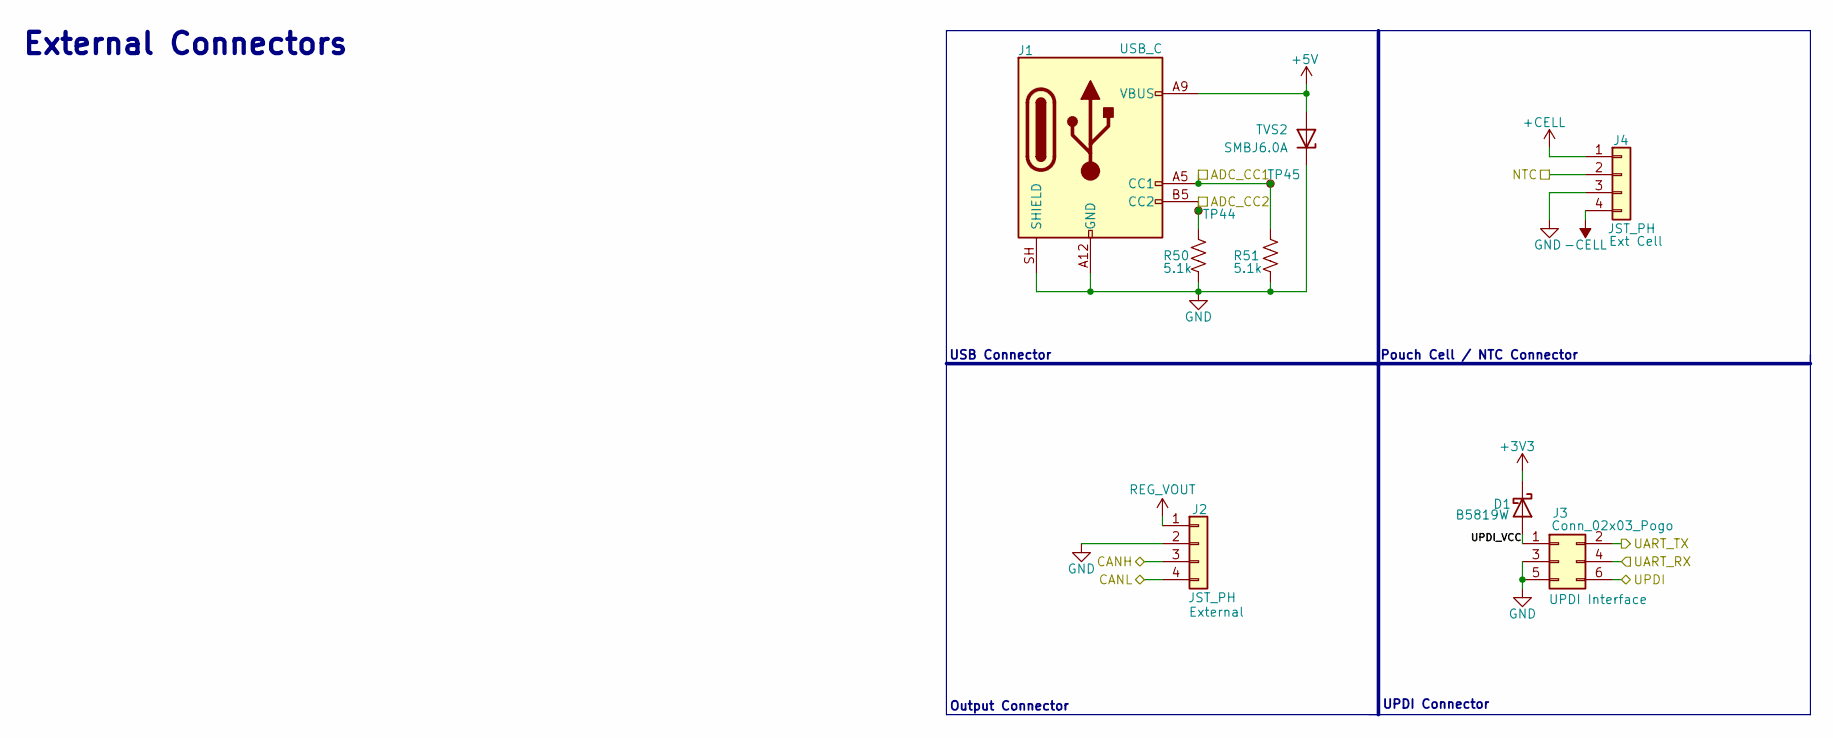
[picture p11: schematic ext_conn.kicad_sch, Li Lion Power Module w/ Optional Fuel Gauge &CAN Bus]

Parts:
D1: B5819W; D_SOD-123; LCSC# C64885
J1: USB_C; USB_C_Receptacle_GCT_USB4125-xx-x-0190_6P_TopMnt_Horizontal
J2, J4: JST_PH; JST_PH_B4B-PH-K_1x04_P2.00mm_Vertical
J3: Conn_02x03_Pogo; PinSocket_2x03_P2.54mm_Vertical
R50, R51: 5.1k; R_0603_1608Metric; MFR# RC0603FR-075K1L; LCSC# C105580
TP44: ADC_CC2; TestPoint_Pad_D1.0mm
TP45: ADC_CC1; TestPoint_Pad_D1.0mm
TVS2: SMBJ6.0A; D_SMB; MFR# SMBJ6.0A; LCSC# C140903

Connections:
+3V3: D1.1 (K); also elsewhere on the board
+5V: J1.A9 (VBUS), J1.B9 (VBUS), TVS2.2 (A); also elsewhere on the board
+CELL: J4.1; also elsewhere on the board
-CELL: J4.4; also elsewhere on the board
/CAN Bus/CANH: J2.3; also elsewhere on the board
/CAN Bus/CANL: J2.4; also elsewhere on the board
/External Connectors/ADC_CC1: J1.A5 (CC1), R51.2, TP45.1 (1_1); also elsewhere on the board
/External Connectors/ADC_CC2: J1.B5 (CC2), R50.2, TP44.1 (1_1); also elsewhere on the board
/External Connectors/UART_RX: J3.4; also elsewhere on the board
/External Connectors/UART_TX: J3.2; also elsewhere on the board
/External Connectors/UPDI: J3.6
/External Connectors/UPDI_VCC: D1.2 (A), J3.1
/MCU/NTC_MCU: J4.2; also elsewhere on the board
GND: J1.A12 (GND), J1.B12 (GND), J1.SH (SHIELD), J2.2, J3.3, J3.5, J4.3, R50.1, R51.1, TVS2.1 (K); also elsewhere on the board
REG_VOUT: J2.1; also elsewhere on the board

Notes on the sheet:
Pouch Cell / NTC Connector
USB Connector
External Connectors
UPDI Connector
Output Connector

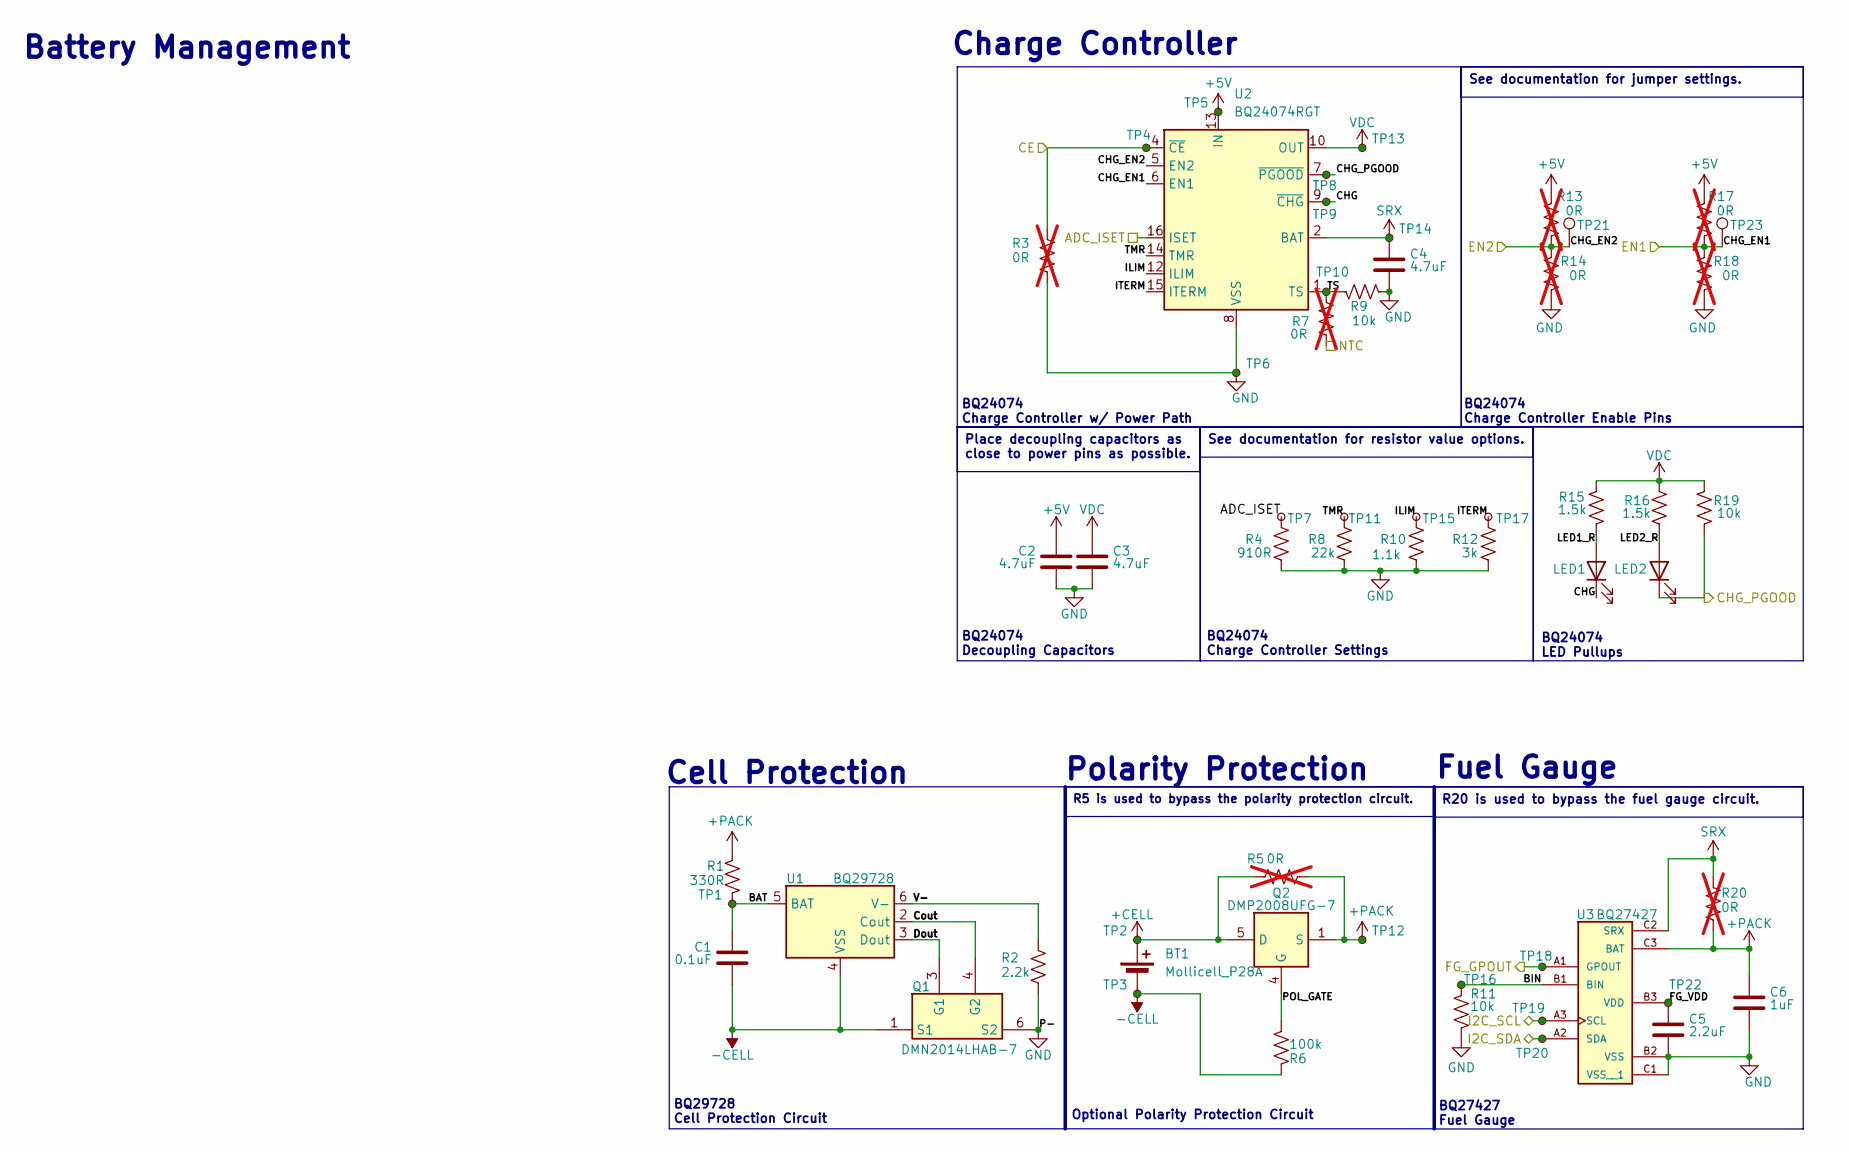
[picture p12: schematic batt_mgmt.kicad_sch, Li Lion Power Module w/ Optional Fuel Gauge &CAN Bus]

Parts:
BT1: Mollicell_P28A; BatteryHolder_HAN_BH-18650-1
C1: 0.1uF; C_0603_1608Metric; LCSC# C14663
C2, C3, C4: 4.7uF; C_0805_2012Metric; LCSC# C96454
C5: 2.2uF; C_0805_2012Metric; LCSC# C1607
C6: 1uF; C_0603_1608Metric; LCSC# C26413
LED1: CHG; LED_0603_1608Metric; LCSC# C2286
LED2: CHG_PGOOD; LED_0603_1608Metric; LCSC# C2286
Q1: DMN2014LHAB-7; U-DFN2030-6; Mouser Part Number 621-DMN2014LHAB-7
Q2: DMP2008UFG-7; Diodes_PowerDI3333-8; Mouser Part Number 621-DMP2008UFG-7
R1: 330R; R_0603_1608Metric; LCSC# C105881
R2: 2.2k; R_0603_1608Metric; LCSC# C114662
R3, R7, R13, R14, R17, R18: 0R; R_0805_2012Metric; LCSC# C54921246; not fitted
R4: 910R; R_0603_1608Metric; LCSC# C185304
R5, R20: 0R; R_1206_3216Metric; MFR# HP06W2J0000T5E; LCSC# C473612; not fitted
R6: 100k; R_0603_1608Metric; LCSC# C14675
R8: 22k; R_0603_1608Metric; LCSC# C114065
R9: 10k; R_0603_1608Metric; MFR# RC0603FR-0710KL; LCSC# C98220
R10: 1.1k; R_0603_1608Metric; LCSC# C137780
R11, R19: 10k; R_0603_1608Metric; LCSC# C98220
R12: 3k; R_0603_1608Metric; LCSC# C126358
R15, R16: 1.5k; R_0603_1608Metric; LCSC# C114680
TP1: BAT; TestPoint_Pad_D1.0mm
TP2: +Cell; TestPoint_Pad_D1.0mm
TP3: -Cell; TestPoint_Pad_D1.0mm
TP4: CE; TestPoint_Pad_D1.0mm
TP5: 5V; TestPoint_Pad_D1.0mm
TP6: GND; TestPoint_Pad_D1.0mm
TP7: ADC_ISET; TestPoint_Pad_D1.0mm
TP8: CHG_PGOOD; TestPoint_Pad_D1.0mm
TP9: CHG; TestPoint_Pad_D1.0mm
TP10: TS; TestPoint_Pad_D1.0mm
TP11: TMR; TestPoint_Pad_D1.0mm
TP12: +Pack; TestPoint_Pad_D1.0mm
TP13: CHG_OUT; TestPoint_Pad_D1.0mm
TP14: SRX; TestPoint_Pad_D1.0mm
TP15: ILIM; TestPoint_Pad_D1.0mm
TP16: BIN; TestPoint_Pad_D1.0mm
TP17: ITERM; TestPoint_Pad_D1.0mm
TP18: FG_GPOUT; TestPoint_Pad_D1.0mm
TP19: I2C_SCL; TestPoint_Pad_D1.0mm
TP20: I2C_SDA; TestPoint_Pad_D1.0mm
TP21: EN2; TestPoint_Pad_D1.0mm
TP22: FG_VDD; TestPoint_Pad_D1.0mm
TP23: EN1; TestPoint_Pad_D1.0mm
U1: BQ29728; WSON-6_1.5x1.5mm_P0.5mm; LCSC# C3682679
U2: BQ24074RGT; VQFN-16-1EP_3x3mm_P0.5mm_EP1.6x1.6mm_ThermalVias; LCSC# C54313
U3: BQ27427; LCSC# C6075475

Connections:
+5V: C2.1, R13.2, R17.2, TP5.1 (1_1), U2.13 (IN); also elsewhere on the board
+CELL: BT1.1 (+), Q2.5 (D), R5.1, TP2.1 (1_1); also elsewhere on the board
+PACK: C6.1, Q2.1 (S), Q2.2 (S), Q2.3 (S), R1.1, R5.2, R20.2, TP12.1 (1_1), U3.C3 (BAT)
-CELL: BT1.2 (-), C1.2, Q1.1 (S1), R6.1, TP3.1 (1_1), U1.4 (VSS); also elsewhere on the board
/Battery Management/ADC_ISET: R4.1, TP7.1 (1_1), U2.16 (ISET); also elsewhere on the board
/Battery Management/BAT: C1.1, R1.2, TP1.1 (1_1), U1.5 (BAT)
/Battery Management/BIN: R11.1, TP16.1 (1_1), U3.B1 (BIN)
/Battery Management/CE: R3.2, TP4.1 (1_1), U2.4 (~CE); also elsewhere on the board
/Battery Management/CHG: LED1.1 (K), TP9.1 (1_1), U2.9 (~CHG)
/Battery Management/CHG_EN1: R17.1, R18.2, TP23.1 (1_1), U2.6 (EN1); also elsewhere on the board
/Battery Management/CHG_EN2: R13.1, R14.2, TP21.1 (1_1), U2.5 (EN2); also elsewhere on the board
/Battery Management/CHG_PGOOD: LED2.1 (K), R19.1, TP8.1 (1_1), U2.7 (~PGOOD); also elsewhere on the board
/Battery Management/Cout: Q1.4 (G2), U1.2 (Cout)
/Battery Management/Dout: Q1.3 (G1), U1.3 (Dout)
/Battery Management/FG_GPOUT: TP18.1 (1_1), U3.A1 (GPOUT); also elsewhere on the board
/Battery Management/FG_VDD: C5.1, TP22.1 (1_1), U3.B3 (VDD)
/Battery Management/I2C_SCL: TP19.1 (1_1), U3.A3 (SCL); also elsewhere on the board
/Battery Management/I2C_SDA: TP20.1 (1_1), U3.A2 (SDA); also elsewhere on the board
/Battery Management/ILIM: R10.1, TP15.1 (1_1), U2.12 (ILIM)
/Battery Management/ITERM: R12.1, TP17.1 (1_1), U2.15 (ITERM)
/Battery Management/LED1_R: LED1.2 (A), R15.1
/Battery Management/LED2_R: LED2.2 (A), R16.1
/Battery Management/POL_GATE: Q2.4 (G), R6.2
/Battery Management/TMR: R8.1, TP11.1 (1_1), U2.14 (TMR)
/Battery Management/TS: R7.2, R9.2, TP10.1 (1_1), U2.1 (TS)
/Battery Management/V-: R2.1, U1.6 (V-)
/MCU/NTC_MCU: R7.1; also elsewhere on the board
GND: C2.2, C3.2, C4.2, C5.2, C6.2, Q1.6 (S2), R2.2, R3.1, R4.2, R8.2, R9.1, R10.2, R11.2, R12.2, R14.1, R18.1, TP6.1 (1_1), U2.8 (VSS), U2.17 (VSS), U3.B2 (VSS), U3.C1 (VSS__1); also elsewhere on the board
SRX: C4.1, R20.1, TP14.1 (1_1), U2.2 (BAT), U2.3 (BAT), U3.C2 (SRX)
VDC: C3.1, R15.2, R16.2, R19.2, TP13.1 (1_1), U2.10 (OUT), U2.11 (OUT); also elsewhere on the board

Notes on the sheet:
Cell Protection
Polarity Protection
BQ27427 Fuel Gauge
Fuel Gauge
Battery Management
BQ29728 Cell Protection Circuit
BQ24074 Decoupling Capacitors
Charge Controller
BQ24074 Charge Controller Settings
Optional Polarity Protection Circuit
BQ24074 LED Pullups
BQ24074 Charge Controller w/ Power Path
BQ24074 Charge Controller Enable Pins
Place decoupling capacitors as close to power pins as possible.
R20 is used to bypass the fuel gauge circuit.
See documentation for jumper settings.
See documentation for resistor value options.
R5 is used to bypass the polarity protection circuit.

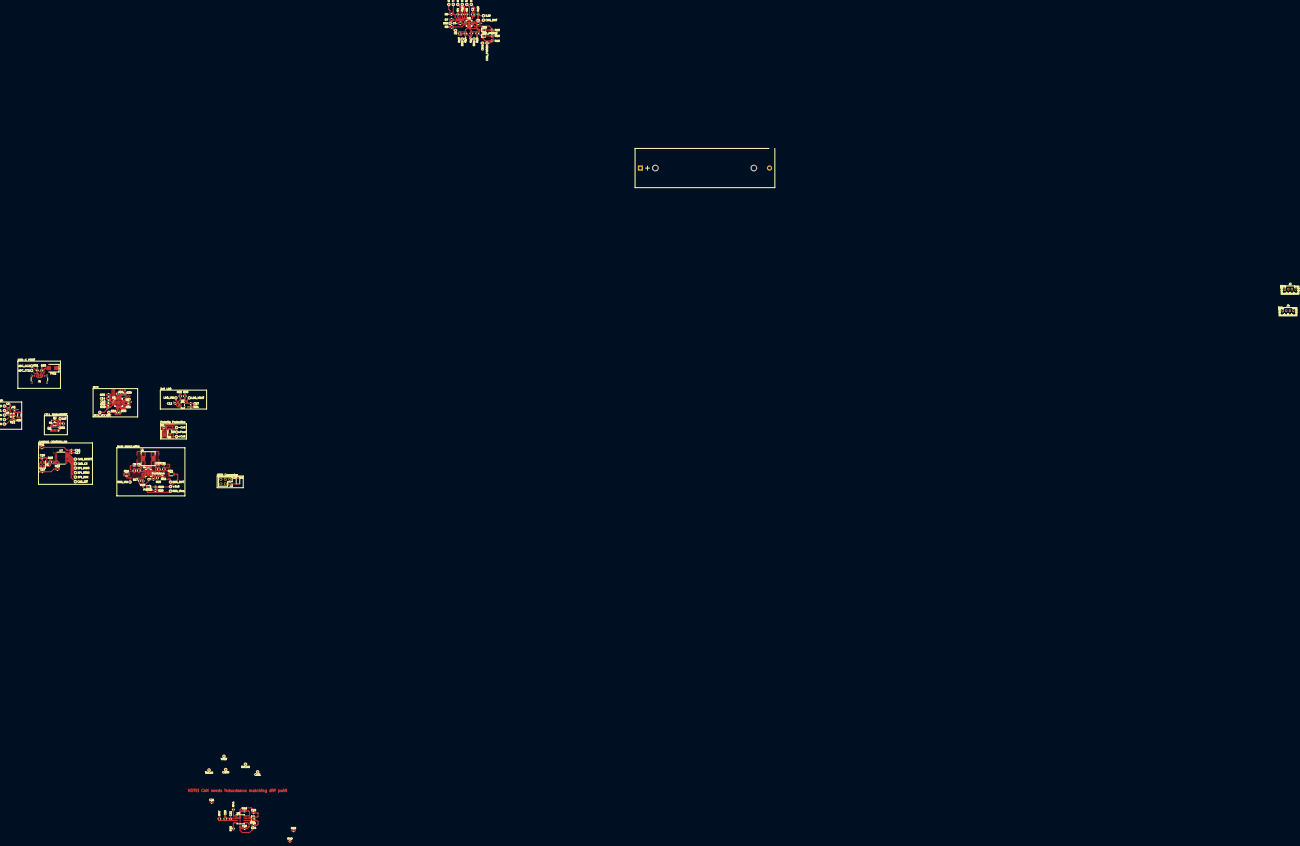
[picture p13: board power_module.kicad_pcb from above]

Board: 4 copper layers, 144 parts (0 on the bottom side), 70 nets.

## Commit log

2026-06-22 Initial commit - project-local libraries
    [CAN.kicad_sch, batt_mgmt.kicad_sch, chrg_conn.kicad_sch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]
2026-06-22 clean up
    [power_module.csv]
2026-06-25 Added Graph & cleaned up title and layout
    [CAN.kicad_sch, batt_mgmt.kicad_sch, ext_conn.kicad_sch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]
2026-07-15 Added labels and schematic PDF among other progress
    [CAN.kicad_sch, batt_mgmt.kicad_sch, charger setttings.ods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]
2026-07-20 Added testpoints
    [CAN.kicad_sch, batt_mgmt.kicad_sch, ext_conn.kicad_sch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]
2026-07-24 Made PDF print correctly
2026-07-26 Partially assigned netclasses WIP
    [CAN.kicad_sch, ext_conn.kicad_sch, mcu.kicad_sch]
2026-07-27 Configured Varients
    [CAN.kicad_sch, batt_mgmt.kicad_sch, ext_conn.kicad_sch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]
2026-07-29 Moved charger configuration resistors to own block
    [batt_mgmt.kicad_sch]
2026-07-29 Arranged functional blocks
    [batt_mgmt.kicad_sch]
2026-08-07 Started work on PCB layout
    [CAN.kicad_sch, batt_mgmt.kicad_sch, ext_conn.kicad_sch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]
2026-10-06 Arranging Passives more effeciently
    [power_module.kicad_pcb]
